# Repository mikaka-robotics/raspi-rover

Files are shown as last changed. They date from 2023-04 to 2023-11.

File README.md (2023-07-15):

# Raspi-Rover

rover_gif

このレポジトリは開発中です。動作の保証はありませんのでご注意ください。

このレポジトリはAIロボット部の開発するロボットについてのレポジトリです。
以下のような情報を含みます。
- ロボットの車体の設計図
- ロボットの回路図
- ロボットの制御プログラム
- ロボットの移動指令プログラム
- ロボットのシュミレーション環境（Gazebo）

TO DO:
- [ ] ロボットの経路追従プログラム
- [ ] ロボットの経路作成プログラム
- [x] ロボットのマッピングのプログラム
- [x] ロボットの自己位置推定のプログラム

## Getting Started
### 組み立て

### arduino
Arduino IDEをインストール。

### ros2
以下の環境で実行を確認しています。他の環境での実行は保証されません。
- Ubuntu 22.04
- ROS2 Humble
  
ロボットは指令を受けて姿勢の指令値を車輪の速度の指令値に変換し、その指令値に基づいて制御部でロボットの車輪の速度を制御しています。

なお、ここでいう制御部は先ほどArduino IDEでESP32にビルドした.inoファイルを指しています。また、指令部は`raspi_ws/src/raspi_rover/raspi_rover/twist_to_radsec_diff.py`を指しています。

指令部はROS 2のTwist型の指令を受け取り、逆運動学で各車輪への指令値に変換した後、制御部に向けて二つの車輪の角速度を送信します。制御部は指令値に基づいて車輪の角速度(rad/sec)を計算しています。

図にすると以下のようになります。

ros2_rover_cmd

以下は実行環境を作成するためのチュートリアルです。

#### Ubuntu22.04をraspberry piにインストールする
Raspberry Piである必要はありませんが、Ubuntu22.04が動作するPCにUbuntu22.04をインストールします。
```
ここに色々入れる（前書いたcodimd）
```
#### ROS2 Humbleをインストールし、依存関係をインストールする
TODO

#### micro-ROSをインストールし、ESP32との通信を確認する
まずはmicro-ROS AgentをホストPC(raspberry pi)にインストールする。
```bash
cd {ros2のwork spaceのパス}
source /opt/ros/$ROS_DISTRO/setup.bash
git clone -b $ROS_DISTRO https://github.com/micro-ROS/micro_ros_setup.git src/micro_ros_setup
rosdep update && rosdep install --from-paths src --ignore-src -y
colcon build
source install/local_setup.bash
```
また以下を実行し、セットアップを完了する。
```bash
ros2 run micro_ros_setup create_agent_ws.sh
ros2 run micro_ros_setup build_agent.sh
source install/local_setup.sh
```
つづいてESP32で実行するraspi_rover_esp32.inoを書きかえてからデプロイする。
ファイルの112行目でwifiのSSIDとpass、さらに接続するホストPC（rasberry pi）のipアドレスを設定する。
```C++
set_microros_wifi_transports("wifi-ssid", "wifi-pass", "192.168.your.ip-addres", 8888);
```
上記を書きかえたら、arduino IDEで書き込み先USB-serial,書き込み形式ESP32-dev moduleを選びデプロイする。
通電中は書き込んだ.inoファイルが実行されるので、ここからはwifi経由でホストPC（raspberry pi）と接続する。
ホストPC(raspberry pi)側で以下を実行し、raspi-ESP32の通信を確立する。
```bash
ros2 run micro_ros_agent micro_ros_agent udp4 --port 8888 -v6
```
トピックを確認する。
```bash
ros2 topic list
```
`/odom`と`/left_radsec`と`/right_radsec`が表示されていれば成功！

#### 本リポジトリをローカルにcloneしてソースコードをダウンロードし、ros2_wsでビルドする
```bash
mkdir Documents/robot
cd Documents/robot
git clone https://github.com/mikaka-robotics/raspi-rover.git
cp raspi-rover/ros2_raspi_rover ~/ros2_ws/src
cp raspi-rover/ros2_raspi_rover_description ~/ros2_ws/src
cd ~/ros2_ws
colcon buid
```
#### ros2-teleop-twist-keyboardでキーボードから指令値を出す
TODO

#### 指令部を立ち上げ、Twist型の指令値を変換し、各車輪の速度へ変換してPublishする
TODO

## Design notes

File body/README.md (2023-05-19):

# 車体

スクリーンショット 2023-05-19 19 41 11

- PlateA.stl
  - 一番下のプレートです。
- PlateB.stl
  - 真ん中のプレートです
- PlateC.stl
  - 一番上のプレートです。raspi 4をねじ止めできるようになっています。
- gia.stl
  - エンコーダー用のギアです。左右で２つ必要。
- tire.stl
  - タイヤです。左右で２つ必要。
- sabo_holder.stl
  - サーボを車体に止めるためのパーツです。そのままだと左車輪用になっています。
  - さらに**左右反転**させた状態で印刷し、右車輪用のパーツも印刷してください。

タイヤとギアについては2mmの精度で印刷したほうが良いです。

## そのほか必要なパーツ

| パーツ | 数 | 備考 |
| --- | --- | --- |
| キャスター | 1 | https://akizukidenshi.com/catalog/g/gK-10372/ |
| 六角シャフト | 1 | www.amazon.co.jp/dp/B08G3PRMCK <br>エンコーダ用の軸です。切断して使います。実際に使うのは2cm*2ほどです。|
| 六角スペーサー | 8 | www.amazon.co.jp/dp/B07JB39SGZ |
| タイヤゴム | 2 | https://akizukidenshi.com/catalog/g/gP-13207/ <br>贅沢にもタイヤゴムだけ剥ぎ取って使います。 |
| 3mmネジ | たくさん | プラネジだと切断して長さを調整できるのでオススメ |

## 組み立て
後ほど説明 & 動画公開予定

スクリーンショット 2023-05-19 19 46 05
スクリーンショット 2023-05-19 19 45 46
スクリーンショット 2023-05-19 19 45 34

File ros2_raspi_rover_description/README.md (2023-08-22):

# raspi_rover_description

このレポジトリはこの[チュートリアル](https://navigation.ros.org/setup_guides/urdf/setup_urdf.html)に基づいて作成されました。

## 依存関係の解決

```bash
sudo apt install ros-humble-joint-state-publisher-gui
sudo apt install ros-humble-xacro
sudo apt install ros-humble-gazebo-ros-pkgs
sudo apt install ros-humble-slam-toolbox
sudo apt install ros-humble-navigation2
sudo apt install ros-humble-nav2-bringup
//必要に応じて
sudo apt install ros-humble-ros-gz
sudo apt install ros-foxy-rmw-cyclonedds-cpp
export export RMW_IMPLEMENTATION=rmw_cyclonedds_cpp 
```

## ビルド

```bash
cd ros2_ws
colcon build --symlink-install
```

## 実行

### ロボットモデルのシュミレーションとデータの可視化

- in teminal1

```bash
ros2 launch ros2_raspi_rover_description display.launch.py use_sim_time:=true
```

gazeboとrviz2が立ち上がり、物理シュミレーションとロボットの内部状態の可視化が始まる。

<details>

<summary>ログ</summary>

```bash
ros2 launch ros2_raspi_rover_description display.launch.py
[INFO] [launch]: All log files can be found below /home/turtlebot/.ros/log/2023-07-11-22-16-37-836094-turtlebot-CFSZ5-2L-6759
[INFO] [launch]: Default logging verbosity is set to INFO
[INFO] [gazebo-1]: process started with pid [6761]
[INFO] [joint_state_publisher-2]: process started with pid [6763]
[INFO] [robot_state_publisher-3]: process started with pid [6765]
[INFO] [spawn_entity.py-4]: process started with pid [6767]
[INFO] [ekf_node-5]: process started with pid [6769]
[INFO] [rviz2-6]: process started with pid [6772]
[rviz2-6] Warning: Ignoring XDG_SESSION_TYPE=wayland on Gnome. Use QT_QPA_PLATFORM=wayland to run on Wayland anyway.
[robot_state_publisher-3] [WARN] [1689081398.381003305] [kdl_parser]: The root link base_link has an inertia specified in the URDF, but KDL does not support a root link with an inertia.  As a workaround, you can add an extra dummy link to your URDF.
[robot_state_publisher-3] [INFO] [1689081398.383196398] [robot_state_publisher]: got segment base_footprint
[robot_state_publisher-3] [INFO] [1689081398.384240422] [robot_state_publisher]: got segment base_link
[robot_state_publisher-3] [INFO] [1689081398.385155106] [robot_state_publisher]: got segment caster
[robot_state_publisher-3] [INFO] [1689081398.385984557] [robot_state_publisher]: got segment caster_cylinder
[robot_state_publisher-3] [INFO] [1689081398.386877932] [robot_state_publisher]: got segment left_wheel
[robot_state_publisher-3] [INFO] [1689081398.387782694] [robot_state_publisher]: got segment lidar_link
[robot_state_publisher-3] [INFO] [1689081398.388720231] [robot_state_publisher]: got segment right_wheel
[joint_state_publisher-2] [INFO] [1689081399.120429785] [joint_state_publisher]: Waiting for robot_description to be published on the robot_description topic...
[spawn_entity.py-4] [INFO] [1689081399.303324831] [spawn_entity]: Spawn Entity started
[spawn_entity.py-4] [INFO] [1689081399.304298002] [spawn_entity]: Loading entity published on topic robot_description
[spawn_entity.py-4] /opt/ros/humble/local/lib/python3.10/dist-packages/rclpy/qos.py:307: UserWarning: DurabilityPolicy.RMW_QOS_POLICY_DURABILITY_TRANSIENT_LOCAL is deprecated. Use DurabilityPolicy.TRANSIENT_LOCAL instead.
[spawn_entity.py-4]   warnings.warn(
[spawn_entity.py-4] [INFO] [1689081399.308522600] [spawn_entity]: Waiting for entity xml on robot_description
[spawn_entity.py-4] [INFO] [1689081399.319738003] [spawn_entity]: Waiting for service /spawn_entity, timeout = 30
[spawn_entity.py-4] [INFO] [1689081399.320560853] [spawn_entity]: Waiting for service /spawn_entity
[gazebo-1] Gazebo multi-robot simulator, version 11.10.2
[gazebo-1] Copyright (C) 2012 Open Source Robotics Foundation.
[gazebo-1] Released under the Apache 2 License.
[gazebo-1] http://gazebosim.org
[gazebo-1] 
[gazebo-1] Gazebo multi-robot simulator, version 11.10.2
[gazebo-1] Copyright (C) 2012 Open Source Robotics Foundation.
[gazebo-1] Released under the Apache 2 License.
[gazebo-1] http://gazebosim.org
[gazebo-1] 
[rviz2-6] [INFO] [1689081399.581675799] [rviz2]: Stereo is NOT SUPPORTED
[rviz2-6] [INFO] [1689081399.581920222] [rviz2]: OpenGl version: 4.6 (GLSL 4.6)
[rviz2-6] [INFO] [1689081399.630054018] [rviz2]: Stereo is NOT SUPPORTED
[spawn_entity.py-4] [INFO] [1689081400.581761534] [spawn_entity]: Calling service /spawn_entity
[spawn_entity.py-4] [INFO] [1689081400.938152551] [spawn_entity]: Spawn status: SpawnEntity: Successfully spawned entity [ros2_raspi_rover]
[gazebo-1] [INFO] [1689081401.066564088] [diff_drive]: Wheel pair 1 separation set to [0.087500m]
[gazebo-1] [INFO] [1689081401.067496899] [diff_drive]: Wheel pair 1 diameter set to [0.060000m]
[gazebo-1] [INFO] [1689081401.069530593] [diff_drive]: Subscribed to [/cmd_vel]
[gazebo-1] [INFO] [1689081401.074315534] [diff_drive]: Advertise odometry on [/odom]
[INFO] [spawn_entity.py-4]: process has finished cleanly [pid 6767]
```

</details>

上記ログと下記画面が出れば成功。

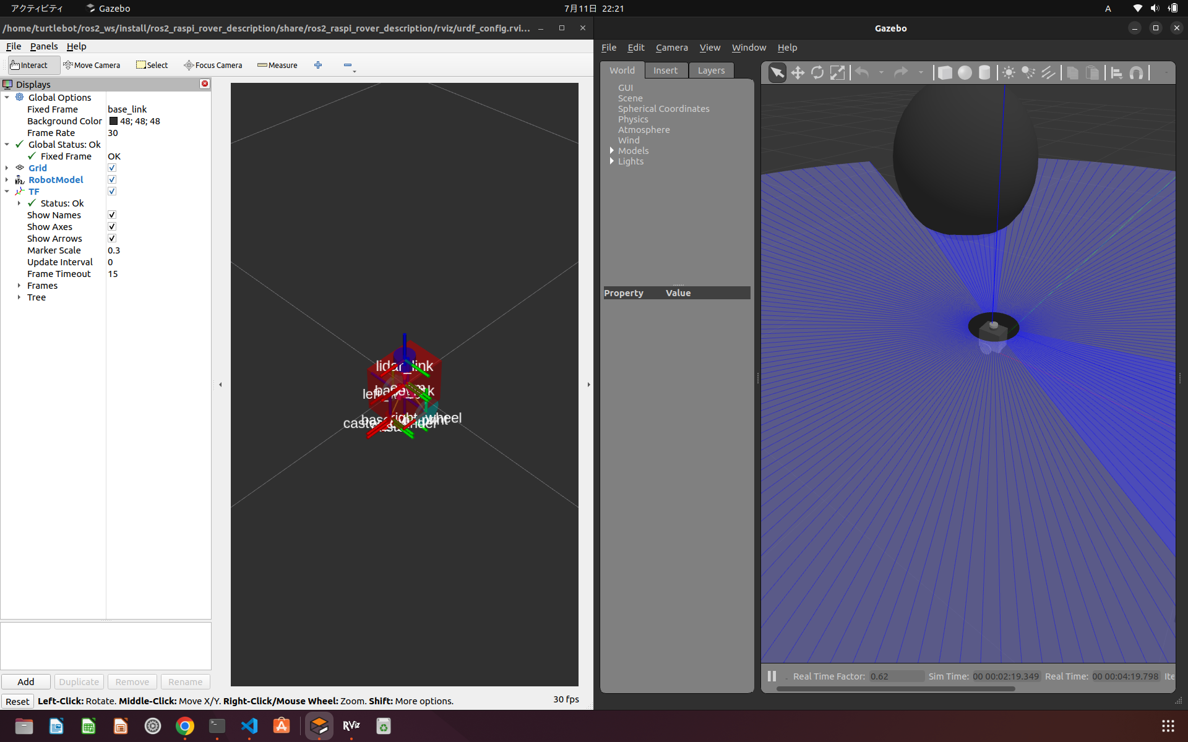
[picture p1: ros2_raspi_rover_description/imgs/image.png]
simulation


URDFの定義が汚いとロボットが転んだり、LIDARが傾いたりする。
慣性モーメントが非現実的というエラーが出る。

### slam_toolboxを使用した自己位置推定と地図作成

- in terminal2

```bash
ros2 launch slam_toolbox online_async_launch.py use_sim_time:=true
```

slamが実行され、自己位置推定と地図作成が開始される。rvizで/mapを追加し可視化すると
既知領域（移動可能）既知領域（障害物）と未知領域の/mapが作成されているのがわかる。
<details>

<summary>ログ</summary>

```bash
[INFO] [launch]: All log files can be found below /home/turtlebot/.ros/log/2023-07-11-22-24-06-148711-turtlebot-CFSZ5-2L-7904
[INFO] [launch]: Default logging verbosity is set to INFO
[INFO] [async_slam_toolbox_node-1]: process started with pid [7907]
[async_slam_toolbox_node-1] [INFO] [1689081847.942501369] [slam_toolbox]: Node using stack size 40000000
[async_slam_toolbox_node-1] [INFO] [1689081848.285260282] [slam_toolbox]: Using solver plugin solver_plugins::CeresSolver
[async_slam_toolbox_node-1] [INFO] [1689081848.286567586] [slam_toolbox]: CeresSolver: Using SCHUR_JACOBI preconditioner.
[async_slam_toolbox_node-1] Info: clipped range threshold to be within minimum and maximum range!
[async_slam_toolbox_node-1] Registering sensor: [Custom Described Lidar]
```

</details>

上記ログと下記画像が出れば成功。

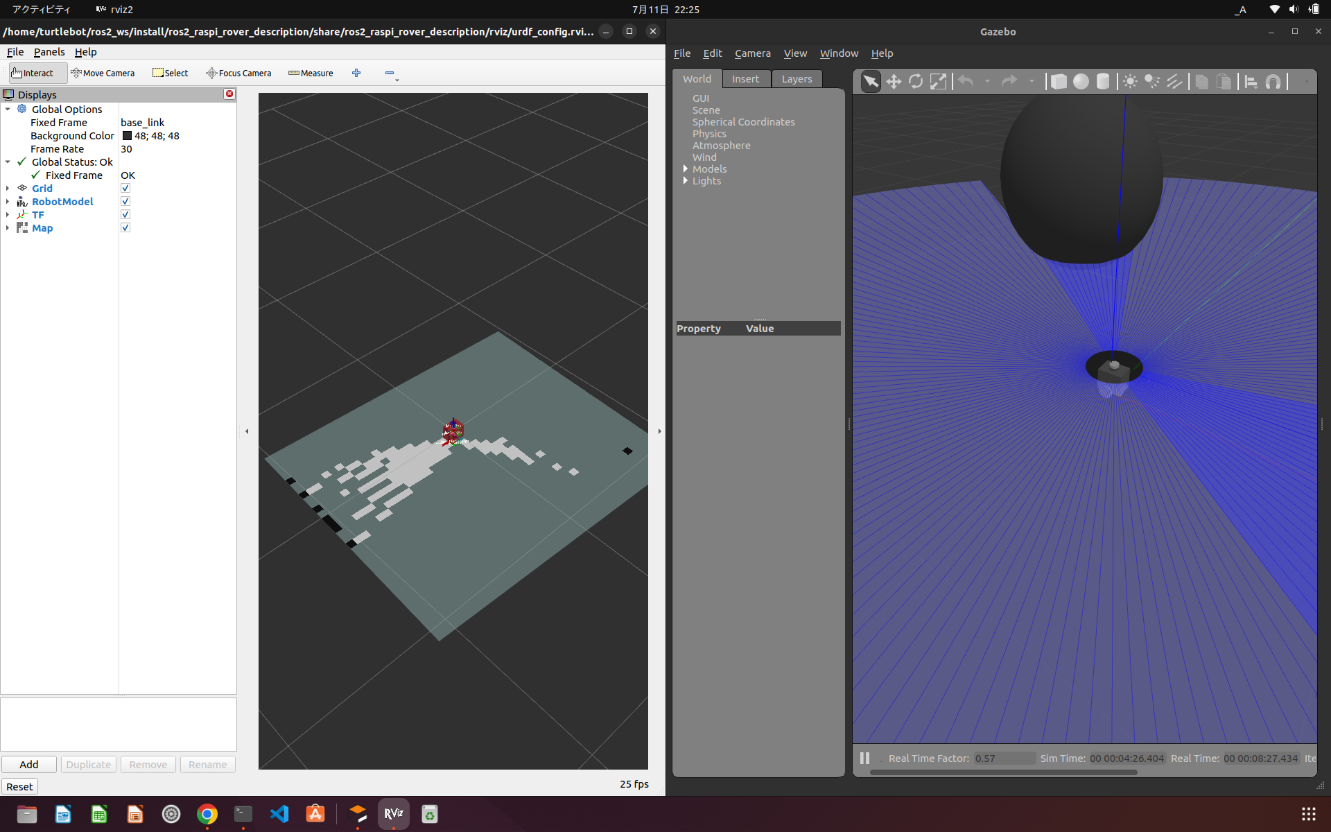
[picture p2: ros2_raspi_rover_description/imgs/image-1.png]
slam_toolbox


/mapがロボットの移動とともに作られるようになる。
なおロボット移動させるときは、以下実行する。

- in terminal3

```bash
ros2 run teleop_twist_keyboard teleop_twist_keyboard
//パッケージがない場合は
sudo apt install ros-humble-teleop-twist-keyboard
```

```bash
ros2 run teleop_twist_keyboard teleop_twist_keyboard 

This node takes keypresses from the keyboard and publishes them
as Twist messages. It works best with a US keyboard layout.
---------------------------
Moving around:
   u    i    o
   j    k    l
   m    ,    .

For Holonomic mode (strafing), hold down the shift key:
---------------------------
   U    I    O
   J    K    L
   M    <    >

t : up (+z)
b : down (-z)

anything else : stop

q/z : increase/decrease max speeds by 10%
w/x : increase/decrease only linear speed by 10%
e/c : increase/decrease only angular speed by 10%

CTRL-C to quit

currently: speed 0.5 turn 1.0
```

このようなログが出る。/cmd_velトピックにnav_msgs/Twist型のメッセージを送るノードを立ち上げた。
速度はデフォルトだと早すぎるので`speed 0.2`位を目安に`x`キーで減速してからコマンド打つ。

### 作成した地図からコストマップを作成する

- in terminal4

```bash
ros2 launch nav2_bringup navigation_launch.py use_sim_time:=true
```

<details>

<summary>ログ</summary>

```bash
[INFO] [launch]: All log files can be found below /home/turtlebot/.ros/log/2023-07-15-20-18-35-577423-turtlebot-CFSZ5-2L-5901
[INFO] [launch]: Default logging verbosity is set to INFO
[INFO] [controller_server-1]: process started with pid [5927]
[INFO] [smoother_server-2]: process started with pid [5929]
[INFO] [planner_server-3]: process started with pid [5931]
[INFO] [behavior_server-4]: process started with pid [5933]
[INFO] [bt_navigator-5]: process started with pid [5935]
[INFO] [waypoint_follower-6]: process started with pid [5937]
[INFO] [velocity_smoother-7]: process started with pid [5939]
[INFO] [lifecycle_manager-8]: process started with pid [5941]
[waypoint_follower-6] [INFO] [1689419922.237441569] [waypoint_follower]: 
[waypoint_follower-6]  waypoint_follower lifecycle node launched. 
[waypoint_follower-6]  Waiting on external lifecycle transitions to activate
[waypoint_follower-6]  See https://design.ros2.org/articles/node_lifecycle.html for more information.
[smoother_server-2] [INFO] [1689419922.276917500] [smoother_server]: 
[smoother_server-2]  smoother_server lifecycle node launched. 
[smoother_server-2]  Waiting on external lifecycle transitions to activate
[smoother_server-2]  See https://design.ros2.org/articles/node_lifecycle.html for more information.
[bt_navigator-5] [INFO] [1689419922.300505799] [bt_navigator]: 
[bt_navigator-5]  bt_navigator lifecycle node launched. 
[bt_navigator-5]  Waiting on external lifecycle transitions to activate
[bt_navigator-5]  See https://design.ros2.org/articles/node_lifecycle.html for more information.
[waypoint_follower-6] [INFO] [1689419922.301062986] [waypoint_follower]: Creating
[bt_navigator-5] [INFO] [1689419922.301731128] [bt_navigator]: Creating
[smoother_server-2] [INFO] [1689419922.437563413] [smoother_server]: Creating smoother server
[planner_server-3] [INFO] [1689419922.545866570] [planner_server]: 
[planner_server-3]  planner_server lifecycle node launched. 
[planner_server-3]  Waiting on external lifecycle transitions to activate
[planner_server-3]  See https://design.ros2.org/articles/node_lifecycle.html for more information.
[planner_server-3] [INFO] [1689419922.660452542] [planner_server]: Creating
[behavior_server-4] [INFO] [1689419922.879208164] [behavior_server]: 
[behavior_server-4]  behavior_server lifecycle node launched. 
[behavior_server-4]  Waiting on external lifecycle transitions to activate
[behavior_server-4]  See https://design.ros2.org/articles/node_lifecycle.html for more information.
[controller_server-1] [INFO] [1689419922.970348322] [controller_server]: 
[controller_server-1]  controller_server lifecycle node launched. 
[controller_server-1]  Waiting on external lifecycle transitions to activate
[controller_server-1]  See https://design.ros2.org/articles/node_lifecycle.html for more information.
[lifecycle_manager-8] [INFO] [1689419922.994013974] [lifecycle_manager_navigation]: Creating
[planner_server-3] [INFO] [1689419922.994654984] [global_costmap.global_costmap]: 
[planner_server-3]  global_costmap lifecycle node launched. 
[planner_server-3]  Waiting on external lifecycle transitions to activate
[planner_server-3]  See https://design.ros2.org/articles/node_lifecycle.html for more information.
[planner_server-3] [INFO] [1689419923.055531382] [global_costmap.global_costmap]: Creating Costmap
[controller_server-1] [INFO] [1689419923.082206754] [controller_server]: Creating controller server
[velocity_smoother-7] [INFO] [1689419923.083369500] [velocity_smoother]: 
[velocity_smoother-7]  velocity_smoother lifecycle node launched. 
[velocity_smoother-7]  Waiting on external lifecycle transitions to activate
[velocity_smoother-7]  See https://design.ros2.org/articles/node_lifecycle.html for more information.
[lifecycle_manager-8] [INFO] [1689419923.293704680] [lifecycle_manager_navigation]: Creating and initializing lifecycle service clients
[controller_server-1] [INFO] [1689419923.439306358] [local_costmap.local_costmap]: 
[controller_server-1]  local_costmap lifecycle node launched. 
[controller_server-1]  Waiting on external lifecycle transitions to activate
[controller_server-1]  See https://design.ros2.org/articles/node_lifecycle.html for more information.
[controller_server-1] [INFO] [1689419923.441419027] [local_costmap.local_costmap]: Creating Costmap
[lifecycle_manager-8] [INFO] [1689419925.173042811] [lifecycle_manager_navigation]: Starting managed nodes bringup...
[lifecycle_manager-8] [INFO] [1689419925.173178543] [lifecycle_manager_navigation]: Configuring controller_server
[controller_server-1] [INFO] [1689419925.180550185] [controller_server]: Configuring controller interface
[controller_server-1] [INFO] [1689419925.182223132] [controller_server]: getting goal checker plugins..
[controller_server-1] [INFO] [1689419925.182774366] [controller_server]: Controller frequency set to 20.0000Hz
[controller_server-1] [INFO] [1689419925.182977193] [local_costmap.local_costmap]: Configuring
[controller_server-1] [INFO] [1689419925.209962205] [local_costmap.local_costmap]: Using plugin "voxel_layer"
[controller_server-1] [INFO] [1689419925.257066650] [local_costmap.local_costmap]: Subscribed to Topics: scan
[controller_server-1] [INFO] [1689419925.328488860] [local_costmap.local_costmap]: Initialized plugin "voxel_layer"
[controller_server-1] [INFO] [1689419925.328573743] [local_costmap.local_costmap]: Using plugin "inflation_layer"
[controller_server-1] [INFO] [1689419925.330400007] [local_costmap.local_costmap]: Initialized plugin "inflation_layer"
[controller_server-1] [INFO] [1689419925.430394367] [controller_server]: Created progress_checker : progress_checker of type nav2_controller::SimpleProgressChecker
[controller_server-1] [INFO] [1689419925.463610875] [controller_server]: Created goal checker : general_goal_checker of type nav2_controller::SimpleGoalChecker
[controller_server-1] [INFO] [1689419925.484851963] [controller_server]: Controller Server has general_goal_checker  goal checkers available.
[controller_server-1] [INFO] [1689419925.538177109] [controller_server]: Created controller : FollowPath of type dwb_core::DWBLocalPlanner
[controller_server-1] [INFO] [1689419925.566788649] [controller_server]: Setting transform_tolerance to 0.200000
[controller_server-1] [INFO] [1689419925.690218917] [controller_server]: Using critic "RotateToGoal" (dwb_critics::RotateToGoalCritic)
[controller_server-1] [INFO] [1689419925.696263162] [controller_server]: Critic plugin initialized
[controller_server-1] [INFO] [1689419925.697062904] [controller_server]: Using critic "Oscillation" (dwb_critics::OscillationCritic)
[controller_server-1] [INFO] [1689419925.700072777] [controller_server]: Critic plugin initialized
[controller_server-1] [INFO] [1689419925.700655289] [controller_server]: Using critic "BaseObstacle" (dwb_critics::BaseObstacleCritic)
[controller_server-1] [INFO] [1689419925.701602336] [controller_server]: Critic plugin initialized
[controller_server-1] [INFO] [1689419925.702233169] [controller_server]: Using critic "GoalAlign" (dwb_critics::GoalAlignCritic)
[controller_server-1] [INFO] [1689419925.710213399] [controller_server]: Critic plugin initialized
[controller_server-1] [INFO] [1689419925.711939905] [controller_server]: Using critic "PathAlign" (dwb_critics::PathAlignCritic)
[controller_server-1] [INFO] [1689419925.715682589] [controller_server]: Critic plugin initialized
[controller_server-1] [INFO] [1689419925.716433640] [controller_server]: Using critic "PathDist" (dwb_critics::PathDistCritic)
[controller_server-1] [INFO] [1689419925.717883357] [controller_server]: Critic plugin initialized
[controller_server-1] [INFO] [1689419925.718887043] [controller_server]: Using critic "GoalDist" (dwb_critics::GoalDistCritic)
[controller_server-1] [INFO] [1689419925.719958373] [controller_server]: Critic plugin initialized
[controller_server-1] [INFO] [1689419925.720020409] [controller_server]: Controller Server has FollowPath  controllers available.
[lifecycle_manager-8] [INFO] [1689419925.787169952] [lifecycle_manager_navigation]: Configuring smoother_server
[smoother_server-2] [INFO] [1689419925.788630514] [smoother_server]: Configuring smoother server
[smoother_server-2] [INFO] [1689419925.903457673] [smoother_server]: Created smoother : simple_smoother of type nav2_smoother::SimpleSmoother
[smoother_server-2] [INFO] [1689419925.939870208] [smoother_server]: Smoother Server has simple_smoother  smoothers available.
[lifecycle_manager-8] [INFO] [1689419926.053778072] [lifecycle_manager_navigation]: Configuring planner_server
[planner_server-3] [INFO] [1689419926.054527229] [planner_server]: Configuring
[planner_server-3] [INFO] [1689419926.054709444] [global_costmap.global_costmap]: Configuring
[planner_server-3] [INFO] [1689419926.102871914] [global_costmap.global_costmap]: Using plugin "static_layer"
[planner_server-3] [INFO] [1689419926.164280664] [global_costmap.global_costmap]: Subscribing to the map topic (/map) with transient local durability
[planner_server-3] [INFO] [1689419926.199054824] [global_costmap.global_costmap]: Initialized plugin "static_layer"
[planner_server-3] [INFO] [1689419926.199124475] [global_costmap.global_costmap]: Using plugin "obstacle_layer"
[planner_server-3] [INFO] [1689419926.200539591] [global_costmap.global_costmap]: Subscribed to Topics: scan
[planner_server-3] [INFO] [1689419926.224952085] [global_costmap.global_costmap]: Initialized plugin "obstacle_layer"
[planner_server-3] [INFO] [1689419926.225117659] [global_costmap.global_costmap]: Using plugin "inflation_layer"
[planner_server-3] [INFO] [1689419926.227922267] [global_costmap.global_costmap]: Initialized plugin "inflation_layer"
[planner_server-3] [INFO] [1689419926.293126836] [global_costmap.global_costmap]: StaticLayer: Resizing costmap to 43 X 35 at 0.050000 m/pix
[planner_server-3] [INFO] [1689419926.298292198] [planner_server]: Created global planner plugin GridBased of type nav2_navfn_planner/NavfnPlanner
[planner_server-3] [INFO] [1689419926.298471059] [planner_server]: Configuring plugin GridBased of type NavfnPlanner
[planner_server-3] [INFO] [1689419926.303659608] [planner_server]: Planner Server has GridBased  planners available.
[lifecycle_manager-8] [INFO] [1689419926.420245003] [lifecycle_manager_navigation]: Configuring behavior_server
[behavior_server-4] [INFO] [1689419926.421333512] [behavior_server]: Configuring
[behavior_server-4] [INFO] [1689419926.595029110] [behavior_server]: Creating behavior plugin spin of type nav2_behaviors/Spin
[behavior_server-4] [INFO] [1689419926.615907398] [behavior_server]: Configuring spin
[behavior_server-4] [INFO] [1689419926.691727445] [behavior_server]: Creating behavior plugin backup of type nav2_behaviors/BackUp
[behavior_server-4] [INFO] [1689419926.699075135] [behavior_server]: Configuring backup
[behavior_server-4] [INFO] [1689419926.762313692] [behavior_server]: Creating behavior plugin drive_on_heading of type nav2_behaviors/DriveOnHeading
[behavior_server-4] [INFO] [1689419926.781026844] [behavior_server]: Configuring drive_on_heading
[behavior_server-4] [INFO] [1689419926.835650146] [behavior_server]: Creating behavior plugin assisted_teleop of type nav2_behaviors/AssistedTeleop
[behavior_server-4] [INFO] [1689419926.869831975] [behavior_server]: Configuring assisted_teleop
[behavior_server-4] [INFO] [1689419926.997254144] [behavior_server]: Creating behavior plugin wait of type nav2_behaviors/Wait
[behavior_server-4] [INFO] [1689419927.019634055] [behavior_server]: Configuring wait
[lifecycle_manager-8] [INFO] [1689419927.053908671] [lifecycle_manager_navigation]: Configuring bt_navigator
[bt_navigator-5] [INFO] [1689419927.055370431] [bt_navigator]: Configuring
[lifecycle_manager-8] [INFO] [1689419927.990699637] [lifecycle_manager_navigation]: Configuring waypoint_follower
[waypoint_follower-6] [INFO] [1689419927.992902450] [waypoint_follower]: Configuring
[waypoint_follower-6] [INFO] [1689419928.133163278] [waypoint_follower]: Created waypoint_task_executor : wait_at_waypoint of type nav2_waypoint_follower::WaitAtWaypoint
[lifecycle_manager-8] [INFO] [1689419928.194341438] [lifecycle_manager_navigation]: Configuring velocity_smoother
[velocity_smoother-7] [INFO] [1689419928.195039319] [velocity_smoother]: Configuring velocity smoother
[lifecycle_manager-8] [INFO] [1689419928.233072930] [lifecycle_manager_navigation]: Activating controller_server
[controller_server-1] [INFO] [1689419928.233637874] [controller_server]: Activating
[controller_server-1] [INFO] [1689419928.233714258] [local_costmap.local_costmap]: Activating
[controller_server-1] [INFO] [1689419928.233745032] [local_costmap.local_costmap]: Checking transform
[controller_server-1] [INFO] [1689419928.234062855] [local_costmap.local_costmap]: start
[controller_server-1] [INFO] [1689419928.487859379] [controller_server]: Creating bond (controller_server) to lifecycle manager.
[lifecycle_manager-8] [INFO] [1689419928.639124475] [lifecycle_manager_navigation]: Server controller_server connected with bond.
[lifecycle_manager-8] [INFO] [1689419928.639274291] [lifecycle_manager_navigation]: Activating smoother_server
[smoother_server-2] [INFO] [1689419928.640909241] [smoother_server]: Activating
[smoother_server-2] [INFO] [1689419928.641130778] [smoother_server]: Creating bond (smoother_server) to lifecycle manager.
[lifecycle_manager-8] [INFO] [1689419928.759665596] [lifecycle_manager_navigation]: Server smoother_server connected with bond.
[lifecycle_manager-8] [INFO] [1689419928.760092828] [lifecycle_manager_navigation]: Activating planner_server
[planner_server-3] [INFO] [1689419928.765279987] [planner_server]: Activating
[planner_server-3] [INFO] [1689419928.765512815] [global_costmap.global_costmap]: Activating
[planner_server-3] [INFO] [1689419928.765581825] [global_costmap.global_costmap]: Checking transform
[planner_server-3] [INFO] [1689419928.765876659] [global_costmap.global_costmap]: start
[planner_server-3] [INFO] [1689419929.771693497] [planner_server]: Activating plugin GridBased of type NavfnPlanner
[planner_server-3] [INFO] [1689419929.781415280] [planner_server]: Creating bond (planner_server) to lifecycle manager.
[lifecycle_manager-8] [INFO] [1689419929.933510759] [lifecycle_manager_navigation]: Server planner_server connected with bond.
[lifecycle_manager-8] [INFO] [1689419929.934008881] [lifecycle_manager_navigation]: Activating behavior_server
[behavior_server-4] [INFO] [1689419929.944137731] [behavior_server]: Activating
[behavior_server-4] [INFO] [1689419929.944246733] [behavior_server]: Activating spin
[behavior_server-4] [INFO] [1689419929.944289529] [behavior_server]: Activating backup
[behavior_server-4] [INFO] [1689419929.944323611] [behavior_server]: Activating drive_on_heading
[behavior_server-4] [INFO] [1689419929.944661737] [behavior_server]: Activating assisted_teleop
[behavior_server-4] [INFO] [1689419929.944716621] [behavior_server]: Activating wait
[behavior_server-4] [INFO] [1689419929.944759829] [behavior_server]: Creating bond (behavior_server) to lifecycle manager.
[lifecycle_manager-8] [INFO] [1689419930.084423980] [lifecycle_manager_navigation]: Server behavior_server connected with bond.
[lifecycle_manager-8] [INFO] [1689419930.084684908] [lifecycle_manager_navigation]: Activating bt_navigator
[bt_navigator-5] [INFO] [1689419930.086398881] [bt_navigator]: Activating
[bt_navigator-5] [INFO] [1689419930.868177731] [bt_navigator]: Creating bond (bt_navigator) to lifecycle manager.
[lifecycle_manager-8] [INFO] [1689419931.050545375] [lifecycle_manager_navigation]: Server bt_navigator connected with bond.
[lifecycle_manager-8] [INFO] [1689419931.060891912] [lifecycle_manager_navigation]: Activating waypoint_follower
[waypoint_follower-6] [INFO] [1689419931.065568753] [waypoint_follower]: Activating
[waypoint_follower-6] [INFO] [1689419931.065675762] [waypoint_follower]: Creating bond (waypoint_follower) to lifecycle manager.
[lifecycle_manager-8] [INFO] [1689419931.298083123] [lifecycle_manager_navigation]: Server waypoint_follower connected with bond.
[lifecycle_manager-8] [INFO] [1689419931.298336480] [lifecycle_manager_navigation]: Activating velocity_smoother
[velocity_smoother-7] [INFO] [1689419931.301811100] [velocity_smoother]: Activating
[velocity_smoother-7] [INFO] [1689419931.302044136] [velocity_smoother]: Creating bond (velocity_smoother) to lifecycle manager.
[lifecycle_manager-8] [INFO] [1689419931.485637947] [lifecycle_manager_navigation]: Server velocity_smoother connected with bond.
[lifecycle_manager-8] [INFO] [1689419931.527892074] [lifecycle_manager_navigation]: Managed nodes are active
[lifecycle_manager-8] [INFO] [1689419931.531749161] [lifecycle_manager_navigation]: Creating bond timer...
```

</details>

ロボットの経路計算に使われるコストマップが表示される。

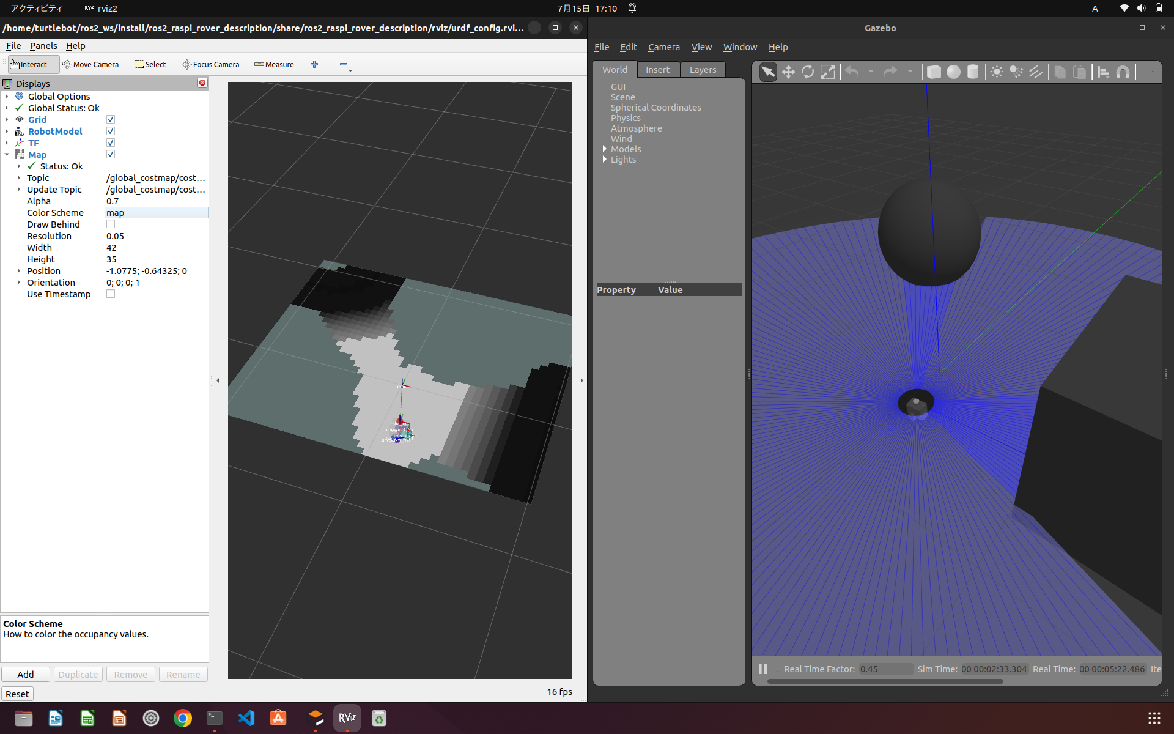
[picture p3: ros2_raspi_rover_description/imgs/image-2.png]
global_costmap

グローバルコストマップの可視化の様子
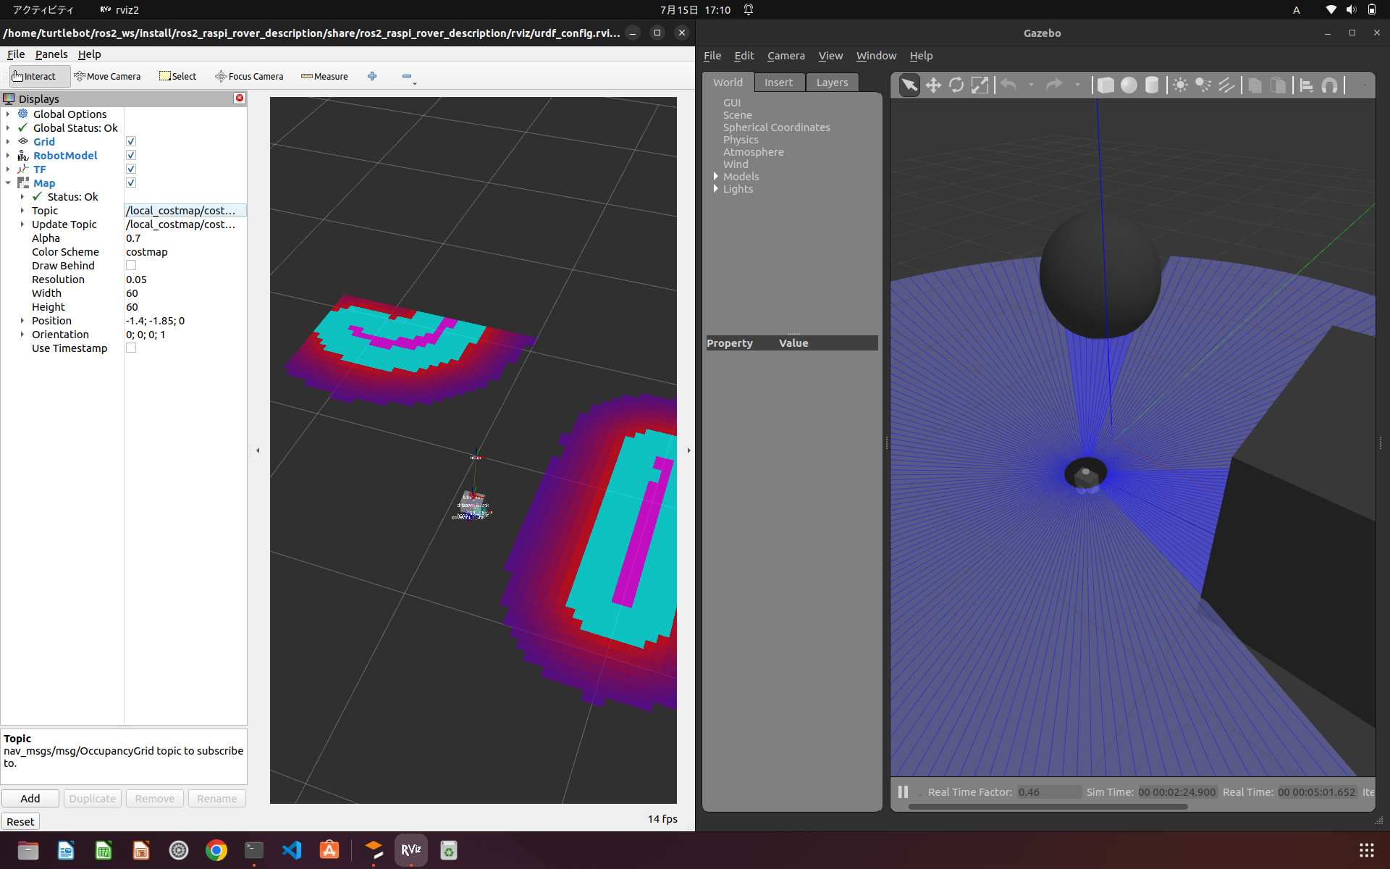
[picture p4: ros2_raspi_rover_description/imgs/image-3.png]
local_costmap

ローカルコストマップの可視化の様子

### Turtlebot3_worldで自律移動シュミレーション

上記の諸々が動作するURDFが書いてあれば以下でnav2が呼び出せる。
nav2の操作方法については別途追記する。

```bash
//turtlebot3のgazeboモデルを読み込みたい
sudo apt install ros-humble-turtlebot3-gazebo
export GAZEBO_MODEL_PATH=$GAZEBO_MODEL_PATH:/opt/ros/humble/share/turtlebot3_gazebo/models
//raspi_roverのモデルでGazeboとRvizを起動したい。（各種設定はURDFに書いてある）
ros2 launch ros2_raspi_rover_description in_tb3.launch.py use_sim_time:=true
//map->base_linkのtf変換をpublishかつ自己位置推定を実行したい
ros2 launch nav2_bringup slam_launch.py use_sim_time:=true
//地図作成しながら自律移動するなら上記、しないなら下記
ros2 launch nav2_bringup localization_launch.py use_sim_time:=true map:=/home/turtlebot/ros2_ws/src/ros2_raspi_rover_description/maps/sim_map.yaml
//Nav2の諸々（behavior,smoother,controller,planner,bt_navigator,waypoint_follwer,vel_smoother,life_cycle）をローンチしたい
ros2 launch nav2_bringup navigation_launch.py use_sim_time:=true
```

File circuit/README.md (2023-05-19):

# 電装

スクリーンショット 2023-05-19 20 05 26
スクリーンショット 2023-05-19 20 05 10

## 必要なパーツ

| 種類 | 数 | 備考 |
| --- | --- | --- |
| ESP32 ＤｅｖＫｉｔＣ | 1 |  https://akizukidenshi.com/catalog/g/gM-15673/  |
| ロータリーエンコーダー | 2 |  https://akizukidenshi.com/catalog/g/gP-15164/ |
| 片側ブレッドボード | 1 | www.amazon.co.jp/dp/B00DSKCS68<br>普通の両側のブレッドボードはESP32devkit-Cだと使えない |
| 2pターミナルブロック | 4 |  https://akizukidenshi.com/catalog/g/gP-01306/  |
| ジャンパー線 | たくさん |  https://akizukidenshi.com/catalog/g/gC-05159/ |

ロータリーエンコーダへの配線のみ、ハンダ付けが必要です。

## ざっくり回路図
あとでちゃんと描きます. 

スクリーンショット 2023-03-24 14 49 23

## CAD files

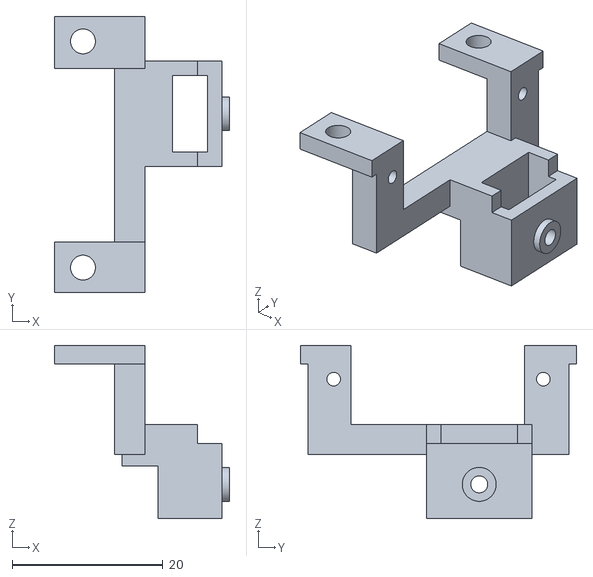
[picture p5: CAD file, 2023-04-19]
body/stl/sabo_holder.stl
23.2 x 36.6 x 23.0

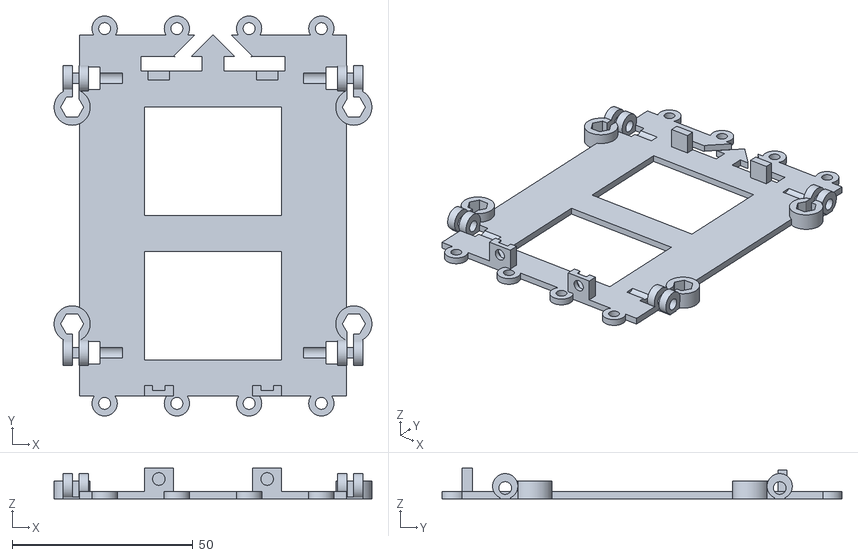
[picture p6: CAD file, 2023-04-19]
body/stl/plateB.stl
88.0 x 110.8 x 8.50

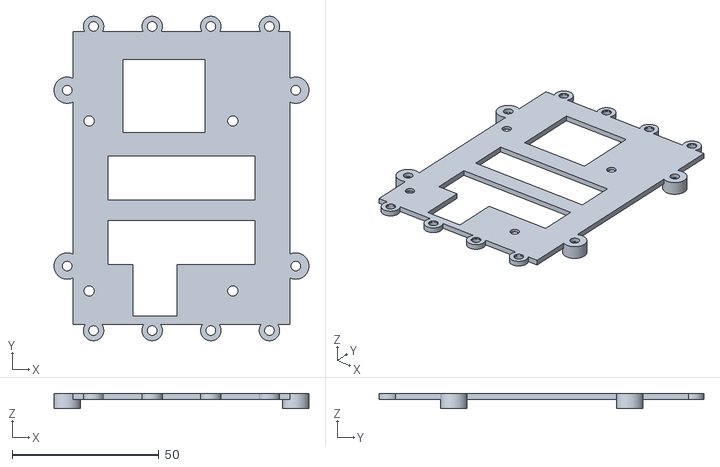
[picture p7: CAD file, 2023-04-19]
body/stl/plateC.stl
87.0 x 110.8 x 5.00

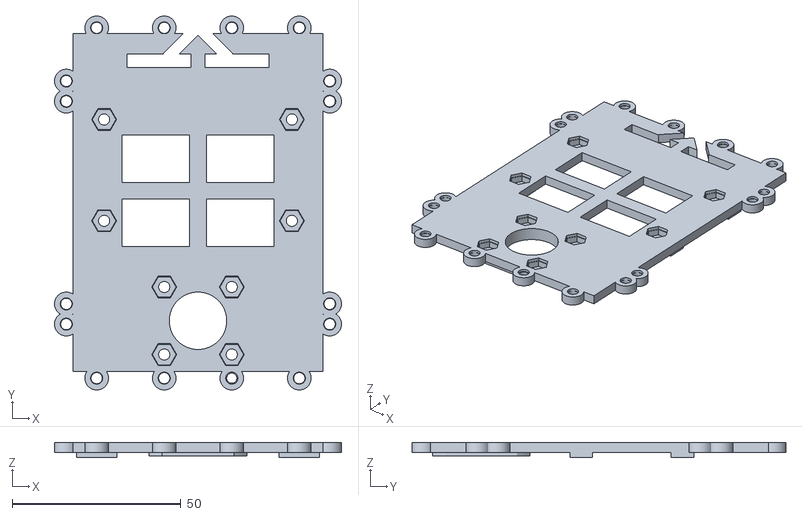
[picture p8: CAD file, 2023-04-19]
body/stl/plateA.stl
85.0 x 110.8 x 4.49

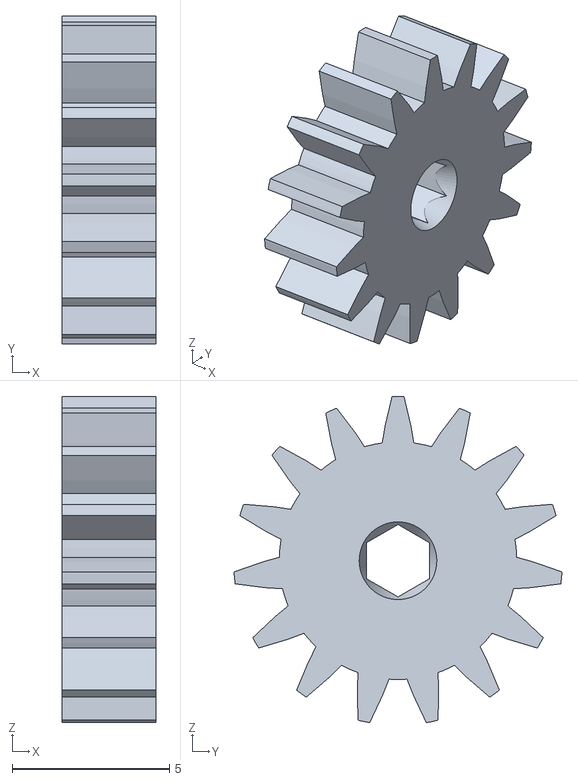
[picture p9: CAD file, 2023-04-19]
body/stl/gia.stl
3.00 x 10.4 x 10.4

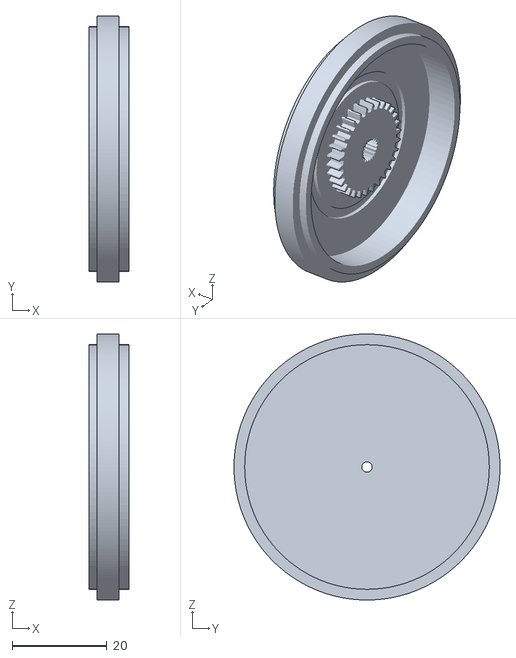
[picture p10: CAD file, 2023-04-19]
body/stl/tire.stl
8.40 x 56.0 x 56.0

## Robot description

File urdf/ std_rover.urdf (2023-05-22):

<robot name="two_wheeled_robot">
  <!-- Base Link -->
  <link name="base_link">
    <visual>
      <geometry>
        <box size="0.11 0.08 0.1"/>
      </geometry>
    </visual>
    <collision>
      <geometry>
        <box size="0.12 0.08 0.1"/>
      </geometry>
    </collision>
    <inertial>
      <mass value="1"/>
      <inertia ixx="0.001" ixy="0.0" ixz="0.0" iyy="0.001" iyz="0.0" izz="0.001"/>
    </inertial>
  </link>
  <!-- LIDAR Link -->
  <link name="lidar">
    <visual>
      <geometry>
        <cylinder radius="0.02" length="0.025"/>
      </geometry>
      <origin rpy="0 0 0" xyz="0 0 0"/>
      <material name="blue">
        <color rgba="0 0 1 1"/>
      </material>
    </visual>
    <collision>
      <geometry>
        <cylinder radius="0.02" length="0.025"/>
      </geometry>
    </collision>
    <inertial>
      <mass value="0.1"/>
      <inertia ixx="0.0001" ixy="0.0" ixz="0.0" iyy="0.0001" iyz="0.0" izz="0.0001"/>
    </inertial>
  </link>
  <!-- Wheel Links -->
  <link name="left_wheel">
    <visual>
      <geometry>
        <cylinder radius="0.03" length="0.0075"/>
      </geometry>
      <material name="black"/>
    </visual>
    <collision>
      <geometry>
        <cylinder radius="0.03" length="0.0075"/>
      </geometry>
    </collision>
    <inertial>
      <mass value="0.1"/>
      <inertia ixx="0.0001" ixy="0.0" ixz="0.0" iyy="0.0001" iyz="0.0" izz="0.0001"/>
    </inertial>
  </link>
  <link name="right_wheel">
    <visual>
      <geometry>
        <cylinder radius="0.03" length="0.0075"/>
      </geometry>
      <material name="black">
        <color rgba="0.2 0.2 0.2 1"/>
      </material>
    </visual>
    <collision>
      <geometry>
        <cylinder radius="0.03" length="0.075"/>
      </geometry>
    </collision>
    <inertial>
      <mass value="0.1"/>
      <inertia ixx="0.0001" ixy="0.0" ixz="0.0" iyy="0.0001" iyz="0.0" izz="0.0001"/>
    </inertial>
  </link>
  <!--Caster Cylinder Link-->
  <link name="caster_cylinder">
    <visual>
      <geometry>
        <cylinder radius="0.01" length="0.025"/>
      </geometry>
    </visual>
    <collision>
      <geometry>
        <cylinder radius="0.01" length="0.025"/>
      </geometry>
    </collision>
    <inertial>
      <mass value="0.05"/>
      <inertia ixx="0.001" ixy="0.0001" ixz="0.0" iyy="0.0" iyz="0.0" izz="0.0"/>
    </inertial>
  </link>
  <!-- Caster Link -->
  <link name="caster">
    <visual>
      <geometry>
        <sphere radius="0.01"/>
      </geometry>
    </visual>
    <collision>
      <geometry>
        <sphere radius="0.01"/>
      </geometry>
    </collision>
    <inertial>
      <mass value="0.05"/>
      <inertia ixx="0.0000125" ixy="0.0" ixz="0.0" iyy="0.0000125" iyz="0.0" izz="0.0000125"/>
    </inertial>
  </link>
  <!-- Joint Definitions -->
  <!-- LIDAR Joint -->
  <joint name="lidar_joint" type="fixed">
    <parent link="base_link"/>
    <child link="lidar"/>
    <origin xyz="0 0 0.0625" rpy="0 0 0"/>
  </joint>
  <joint name="left_wheel_joint" type="continuous">
    <parent link="base_link"/>
    <child link="left_wheel"/>
    <origin xyz="-0.0125 -0.04375 -0.05" rpy="1.57075 0 0"/>
    <axis xyz="0 1 0"/>
  </joint>
  <joint name="right_wheel_joint" type="continuous">
    <parent link="base_link"/>
    <child link="right_wheel"/>
    <origin xyz="-0.0125 0.04375 -0.05" rpy="1.57075 0 0"/>
    <axis xyz="0 1 0"/>
  </joint>
  <joint name="cylinder_joint" type="fixed">
    <parent link="base_link"/>
    <child link="caster_cylinder"/>
    <origin xyz="0.0375 0 -0.05125" rpy="0 0 0"/>
    <axis xyz="0 1 0"/>
  </joint>
  <joint name="caster_joint" type="floating">
    <parent link="caster_cylinder"/>
    <child link="caster"/>
    <origin xyz="0 0 -0.0125" rpy="0 0 0"/>
  </joint>
</robot>

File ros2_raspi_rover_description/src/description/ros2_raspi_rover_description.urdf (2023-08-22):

<?xml version="1.0"?>
<robot name="ros2_raspi_rover" xmlns:xacro="http://ros.org/wiki/xacro">

  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
  <xacro:property name="base_width" value="0.0800"/>
  <xacro:property name="base_length" value="0.1100"/>
  <xacro:property name="base_height" value="0.0800"/>

  <xacro:property name="wheel_radius" value="0.0300"/>
  <xacro:property name="wheel_width" value="0.02"/>
  <xacro:property name="wheel_ygap" value="0.00375"/>
  <xacro:property name="wheel_zoff" value="0.0500"/>
  <xacro:property name="wheel_xoff" value="0.0125"/>

  <xacro:property name="caster_cylinder_xoff" value="0.0375"/>
  <xacro:property name="caster_radius" value="0.01"/>
  <xacro:property name="caster_cylinder_length" value="0.02"/>

  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
  <xacro:macro name="box_inertia" params="m w h d">
    <inertial>
      <origin xyz="0 0 0" rpy="${pi/2} 0 ${pi/2}"/>      
      <mass value="${m}"/>
      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
    </inertial>
  </xacro:macro>

  <xacro:macro name="cylinder_inertia" params="m r h">
    <inertial>
      <origin xyz="0 0 0" rpy="${pi/2} 0 0" />      
      <mass value="${m}"/>
      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 
    </inertial>
  </xacro:macro>

  <xacro:macro name="sphere_inertia" params="m r">
    <inertial>
      <mass value="${m}"/>
      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
    </inertial>
  </xacro:macro>
  
  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
  <link name="base_link">
    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

    <xacro:box_inertia m="1" w="${base_width}" d="${base_length}" h="${base_height}"/>
  </link>
  
  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
  <link name="base_footprint">
  	<xacro:box_inertia m="0" w="0" d="0" h="0"/>
  </link>

  <joint name="base_joint" type="fixed">
    <parent link="base_link"/>
    <child link="base_footprint"/>
    <origin xyz="0.0 0.0 ${-(wheel_radius+wheel_zoff)}" rpy="0 0 0"/>
  </joint>

  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
  <xacro:macro name="wheel" params="prefix x_reflect y_reflect">
    <link name="${prefix}_link">
      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

      <xacro:cylinder_inertia m="0.005" r="${wheel_radius}" h="${wheel_width}"/>
    </link>

    <joint name="${prefix}_joint" type="continuous">
      <parent link="base_link"/>
      <child link="${prefix}_link"/>
      <origin xyz="${x_reflect*wheel_xoff} ${y_reflect*(base_width/2+wheel_ygap)} ${-wheel_zoff}" rpy="0 0 0"/>
      <axis xyz="0 1 0"/>
    </joint>
  </xacro:macro>

  <xacro:wheel prefix="left_wheel" x_reflect="-1" y_reflect="1" />
  <xacro:wheel prefix="right_wheel" x_reflect="-1" y_reflect="-1" />

  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
  

  <link name="front_caster">
    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

    <xacro:sphere_inertia m="0.2" r="${(wheel_radius+wheel_zoff-(base_height/2))}"/>
  </link>

  <joint name="caster_joint" type="fixed">
    <parent link="base_link"/>
    <child link="front_caster"/>
    <origin xyz="${caster_cylinder_xoff} 0.0 ${-(base_height/2)}" rpy="0 0 0"/>
  </joint>

  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
  <link name="lidar_link">
    <inertial>
      <origin xyz="0 0 0" rpy="0 0 0"/>
      <mass value="0.1"/>
      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
    </inertial>

    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
  </link>
    
  <joint name="lidar_joint" type="fixed">
    <parent link="base_link"/>
    <child link="lidar_link"/>
    <origin xyz="0 0 0.062" rpy="0 0 0"/>
  </joint>
    
  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
</robot>

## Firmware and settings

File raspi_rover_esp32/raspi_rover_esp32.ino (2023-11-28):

#include <micro_ros_arduino.h>
#include <ESP32Servo.h>
#include <ESP32Encoder.h>

#include <stdio.h>
#include <rcl/rcl.h>
#include <rcl/error_handling.h>
#include <rclc/rclc.h>
#include <rclc/executor.h>

#include <std_msgs/msg/float64.h>
#include <std_msgs/msg/string.h>

#include <nav_msgs/msg/odometry.h>
#include <geometry_msgs/msg/twist.h>

#if !defined(ESP32) && !defined(TARGET_PORTENTA_H7_M7) && !defined(ARDUINO_NANO_RP2040_CONNECT)
#error This example is only avaible for Arduino Portenta, Arduino Nano RP2040 Connect and ESP32 Dev module
#endif

#define STR_SIZE (100) //最大の受信文字数

TaskHandle_t xTask1;

rcl_publisher_t publisher_right_float64;
rcl_publisher_t publisher_left_float64;
rcl_publisher_t odom_publisher;

nav_msgs__msg__Odometry msg_odom;
std_msgs__msg__Float64 msg_left_speed_float64;
std_msgs__msg__Float64 msg_right_speed_float64;

rcl_subscription_t sub_target_left_speed_float64;
rcl_subscription_t sub_target_right_speed_float64;
std_msgs__msg__Float64 msg_target_left_speed_float64;
std_msgs__msg__Float64 msg_target_right_speed_float64;

rclc_support_t support;
rcl_allocator_t allocator;
rclc_executor_t executor;
rcl_node_t node;


#define LED_PIN 13

#define RCCHECK(fn) { rcl_ret_t temp_rc = fn; if((temp_rc != RCL_RET_OK)){error_loop();}}
#define RCSOFTCHECK(fn) { rcl_ret_t temp_rc = fn; if((temp_rc != RCL_RET_OK)){}}

Servo servo_left;
Servo servo_right;

ESP32Encoder encoder_left;
ESP32Encoder encoder_right;

// 左右のモータPWM信号に使用するピンを定義
const int LEFT_MOTOR_PWM_PIN = 33;
const int RIGHT_MOTOR_PWM_PIN = 32;


// エンコーダカウントとラジアン/度の変換係数を定義
const double DEGREE_PER_ENCODER_COUNT = 3.75;
const double RADIAN_PER_ENCODER_COUNT = 0.06544985;

// ロボットのホイールベースを定義
const double WHEEL_BASE = 0.1;

// PID制御器のゲインを定義
const double KP_GAIN_right = 1.9;
const double KI_GAIN_right = 0.3;
const double KD_GAIN_right = 0.007;

// PID制御器のゲインを定義
const double KP_GAIN_left = 1.9;
const double KI_GAIN_left = 0.3;
const double KD_GAIN_left = 0.007;

double target_left_radsec=0;
double target_right_radsec=0;

double left_radsec=0;
double right_radsec=0;

double tire_radius = 0.03;
double dt=1;

void error_loop(){
  while(1){
    digitalWrite(LED_PIN, !digitalRead(LED_PIN));
    delay(100);
  }
}


void setup() {

   Serial.begin(115200);
   delay(100);
   Serial.println("Start Program!");
   
   servo_left.setPeriodHertz(50);
   servo_right.setPeriodHertz(50);
   servo_left.attach(LEFT_MOTOR_PWM_PIN, 500, 2500); 
   servo_right.attach(RIGHT_MOTOR_PWM_PIN, 500, 2500); 

   servo_left.write(90);
   servo_right.write(90);

   ESP32Encoder::useInternalWeakPullResistors=UP;
   encoder_left.attachHalfQuad(2, 15);
   encoder_right.attachHalfQuad(14, 12);
  
  //set_microros_wifi_transports("ASANOwifi", "yukiwarisou", "192.168.37.199", 8888);
  set_microros_wifi_transports("Buffalo-G-42A0", "bt5adcdkgcrjj", "192.168.11.8", 8888);

  pinMode(LED_PIN, OUTPUT);
  digitalWrite(LED_PIN, HIGH);

  delay(2000);

  allocator = rcl_get_default_allocator();

  //create init_options
  RCCHECK(rclc_support_init(&support, 0, NULL, &allocator));

  // create node
  RCCHECK(rclc_node_init_default(&node, "micro_ros_arduino_wifi_node", "", &support));

  // create publisher
  RCCHECK(rclc_publisher_init_best_effort(
    &publisher_right_float64,
    &node,
    ROSIDL_GET_MSG_TYPE_SUPPORT(std_msgs, msg, Float64),
    "right_radsec"));

  RCCHECK(rclc_publisher_init_best_effort(
    &publisher_left_float64,
    &node,
    ROSIDL_GET_MSG_TYPE_SUPPORT(std_msgs, msg, Float64),
    "left_radsec"));

  RCCHECK(rclc_publisher_init_default(
      &odom_publisher,
      &node,
      ROSIDL_GET_MSG_TYPE_SUPPORT(nav_msgs, msg, Odometry),
      "wheel_odom"));
    
  // Subscriber
  RCCHECK(rclc_subscription_init_best_effort(
    &sub_target_left_speed_float64, 
    &node,
    ROSIDL_GET_MSG_TYPE_SUPPORT(std_msgs, msg, Float64),
    "target_left_radsec")
   );

  // Subscriber
  RCCHECK(rclc_subscription_init_best_effort(
    &sub_target_right_speed_float64, 
    &node,
    ROSIDL_GET_MSG_TYPE_SUPPORT(std_msgs, msg, Float64),
    "target_right_radsec")
   );

  rclc_executor_init(&executor, &support.context, 2, &allocator);
  rclc_executor_add_subscription(&executor, &sub_target_left_speed_float64, &msg_target_left_speed_float64, 
                   &callback_target_left_speed, ON_NEW_DATA);
  rclc_executor_add_subscription(&executor, &sub_target_right_speed_float64, &msg_target_right_speed_float64, 
                   &callback_target_right_speed, ON_NEW_DATA);


  xTaskCreatePinnedToCore(
      task_controller,
      "task_controller",
      8192,
      NULL,
      1,
      &xTask1,
      1
    );

}

unsigned long now;
unsigned long starttime1 = 0;
static long leftPwm = 90;
static long rightPwm = 90;

void task_controller(void *pvParameters){
  while (1) {
    now = millis();

    dt = (now - starttime1)/1000.; //sec
    static long prevLeftEncoderCount = 0;
    static long prevRightEncoderCount = 0;
    long leftEncoderCount = -encoder_left.getCount();
    long rightEncoderCount = encoder_right.getCount();   

    // 左右のエンコーダカウント数の差分から、左右のホイールの速度を算出
    long deltaLeftEncoderCount = leftEncoderCount - prevLeftEncoderCount;
    long deltaRightEncoderCount = rightEncoderCount - prevRightEncoderCount;

    prevLeftEncoderCount = leftEncoderCount;
    prevRightEncoderCount = rightEncoderCount;
    left_radsec = (deltaLeftEncoderCount * RADIAN_PER_ENCODER_COUNT) / dt;
    right_radsec = (deltaRightEncoderCount * RADIAN_PER_ENCODER_COUNT) / dt;

    // 左右のホイール速度と目標角速度の差分から、左右のモータ制御に使用するエラーを算出
    double leftError = target_left_radsec - left_radsec;
    double rightError = target_right_radsec - right_radsec;

    // PID制御
    // 前回のエラーを保存
    static double leftPrevError = 0.0;
    static double rightPrevError = 0.0;

    // 前回のエラーと積分値から、微分値を算出
    static double leftIntegral = 0.0;
    static double rightIntegral = 0.0;
    leftIntegral += leftError * dt;
    rightIntegral += rightError * dt;
    double leftDerivative = (leftError - leftPrevError) / dt;
    double rightDerivative = (rightError - rightPrevError) / dt;
    leftPrevError = leftError;
    rightPrevError = rightError;

    // PID制御によって算出された制御値から、左右のモータのPWM値を計算
    double leftControl = KP_GAIN_left * leftError + KI_GAIN_left * leftIntegral + KD_GAIN_left * leftDerivative;
    double rightControl = KP_GAIN_right * rightError + KI_GAIN_right * rightIntegral + KD_GAIN_right * rightDerivative;
    leftPwm = leftPwm + leftControl;
    rightPwm = rightPwm - rightControl;

    // PWM値を所定の範囲に制限
    leftPwm = constrain(leftPwm, 0, 180);
    rightPwm = constrain(rightPwm, 0, 180);

    

    // 左右のモータにPWM値を出力
    servo_left.write(leftPwm);
    servo_right.write(rightPwm); 

    starttime1 = now;

    vTaskDelay(pdMS_TO_TICKS(100));
  }
}

void callback_target_left_speed(const void *raw_msg){
    std_msgs__msg__Float64 *msg = (std_msgs__msg__Float64 *)raw_msg;
    target_left_radsec = msg->data;
}

void callback_target_right_speed(const void *raw_msg){
    std_msgs__msg__Float64 *msg = (std_msgs__msg__Float64 *)raw_msg;
    target_right_radsec = msg->data;
}




void loop() {

    delay(10);

    RCSOFTCHECK(rclc_executor_spin_some(&executor, RCL_MS_TO_NS(200)));

    // オドメトリの更新
    double leftDistance = left_radsec * dt;
    double rightDistance = right_radsec * dt;
    double deltaDistance = (leftDistance + rightDistance) / 2.0;
    double deltaTheta = (rightDistance - leftDistance) / WHEEL_BASE;

    // 現在の位置と向きを更新
    static double xPos = 0.0;
    static double yPos = 0.0;
    static double theta = 0.0;
    theta += deltaTheta;
    xPos += deltaDistance * cos(theta);
    yPos += deltaDistance * sin(theta);

    // オドメトリメッセージを更新
    msg_odom.pose.pose.position.x = xPos;
    msg_odom.pose.pose.position.y = yPos;
    msg_odom.pose.pose.position.z = 0.0;
    msg_odom.pose.pose.orientation.x = 0.0;
    msg_odom.pose.pose.orientation.y = 0.0;
    msg_odom.pose.pose.orientation.z = sin(theta / 2.0);
    msg_odom.pose.pose.orientation.w = cos(theta / 2.0);
    msg_odom.twist.twist.linear.x = deltaDistance / dt;
    msg_odom.twist.twist.angular.z = deltaTheta / dt;
    
    // オドメトリメッセージのheader.stampに設定
    // headerフィールドを設定
    uint32_t now = millis();
    msg_odom.header.stamp.sec = now / 1000; // 秒単位
    msg_odom.header.stamp.nanosec = (now % 1000) * 1e6; // ナノ秒単位
    // frame_idを設定
    msg_odom.header.frame_id.data = (char *)"odom";
    msg_odom.header.frame_id.size = strlen("odom");
    msg_odom.header.frame_id.capacity = strlen("odom") + 1;
    // child_frame_idを設定
    msg_odom.child_frame_id.data = (char *)"base_link";
    msg_odom.child_frame_id.size = strlen("base_link");
    msg_odom.child_frame_id.capacity = strlen("base_link") + 1;

    msg_left_speed_float64.data = left_radsec;
    msg_right_speed_float64.data = right_radsec;
        
    RCSOFTCHECK(rcl_publish(&publisher_right_float64, &msg_right_speed_float64, NULL));
    RCSOFTCHECK(rcl_publish(&publisher_left_float64, &msg_left_speed_float64, NULL));
    RCSOFTCHECK(rcl_publish(&odom_publisher, &msg_odom, NULL));
      

}

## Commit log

2023-04-19 stlファイルを追加しました
    [gia.stl, option_carrier.stl, option_carrier_joint.stl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]
2023-04-19 gitignoreを追加
2023-04-19 ゴミを除去
2023-05-19 Update README.md
    軽微な修正
2023-05-19 add circuit folder
2023-05-20 Update README.md
    cmd_velの流れを追記
2023-05-22 最初のURDFを追加
    [std_rover.urdf]
2023-07-06 base_footprintを付記
    [std_rover.urdf, std_rover.urdf.xacro]
2023-07-06 デバッグ
    [std_rover.urdf, std_rover.urdf.xacro]
2023-07-06 チュートリアルに従って変更
    [std_rover.urdf, std_rover.urdf.xacro]
2023-07-08 スペルミスを修正
    [std_rover.urdf, std_rover.urdf.xacro]
2023-07-08 add gazebo setting and launch file
    [ros2_raspi_rover.urdf.xacro, ros2_raspi_rover_description.urdf]
2023-07-09 revise urdf
    [ros2_raspi_rover_description.urdf, ros2_raspi_rover_description.urdf.xacro]
2023-07-09 ロボットが水平じゃなかったので修正
    [ros2_raspi_rover_description.urdf, ros2_raspi_rover_description.urdf.xacro]
2023-07-09 トピック名を修正し、esp32と一致させる
2023-07-09 odomは汎用的な名前なので固定
2023-07-10 READMEを更新
2023-07-15 nav2でcostmap作成可能にした
    [my_world.sdf, ros2_raspi_rover_description.urdf, ros2_raspi_rover_description.urdf.xacro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]
2023-07-15 readmeにnav2でcosmap作成までを追加
2023-07-24 readmeを見やすくする
2023-08-22 nav2の各種パッケージを実行するためのパラメーターファイルを追加
2023-08-22 urdfの設定の軽微な修正
    [ros2_raspi_rover_description.urdf]
2023-08-22 nav2実行時のrviz2のデフォルト表示設定
2023-08-22 turtlebot3用のシミュレーション環境に今回作成したモデルを表示するための設定と実行ファイル
2023-08-22 nav2用のmapの設定。作成済みの地図で自律移動するための変更。
2023-08-22 nav2を作成したモデルで実行するための手順を追加
2023-08-22 nav2の各種パッケージを実行するための変更
    [my_world.sdf]
2023-08-22 nav2を動作させるコマンドを追加
2023-11-28 odometoryにheaderを追加
2024-01-04 nav2を実行できる設定が完了
